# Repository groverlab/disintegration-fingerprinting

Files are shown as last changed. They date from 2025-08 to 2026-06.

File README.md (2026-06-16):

# Disintegration Fingerprinting: A Low-Cost and User-Friendly Tool for Identifying Substandard and Falsified Solid-Dosage Medicines

Ishmam Fatima, Oscar Fajardo, Canhui Liu, Harshith Sadhu, and William H. Grover, *Analytical Chemistry* 98 (12), 8871-8892 (2026).
https://doi.org/10.1021/acs.analchem.5c05418

## Usage

If it's not already installed, install *uv* 

MacOS and Linux:

```bash
curl -LsSf https://astral.sh/uv/install.sh | sh
```

Windows:

```powershell
powershell -ExecutionPolicy ByPass -c "irm https://astral.sh/uv/install.ps1 | iex"
```

Program Arduino using the [Arduino IDE](https://www.arduino.cc/en/software/#ide) and the file in df-arduino/df-arduino.ino 

Run acquisition code using

```bash
uv run df-acquire.py
```

Results will be safed in comments.json.gz.

Analyze results using

```base
uv run df-analyze.py path_to_directory
```

where `path_to_directory` is the path to the directory containing the data files to be analyzed.

To recreate all data analysis in the paper, run

```bash
./build.sh
```

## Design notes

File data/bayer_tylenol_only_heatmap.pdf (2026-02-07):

Difference score Tylenol 100248 2027/03 British Columbia

Tylenol EFA114 2028/04 California
Tylenol EFA114 2028/04 Washington

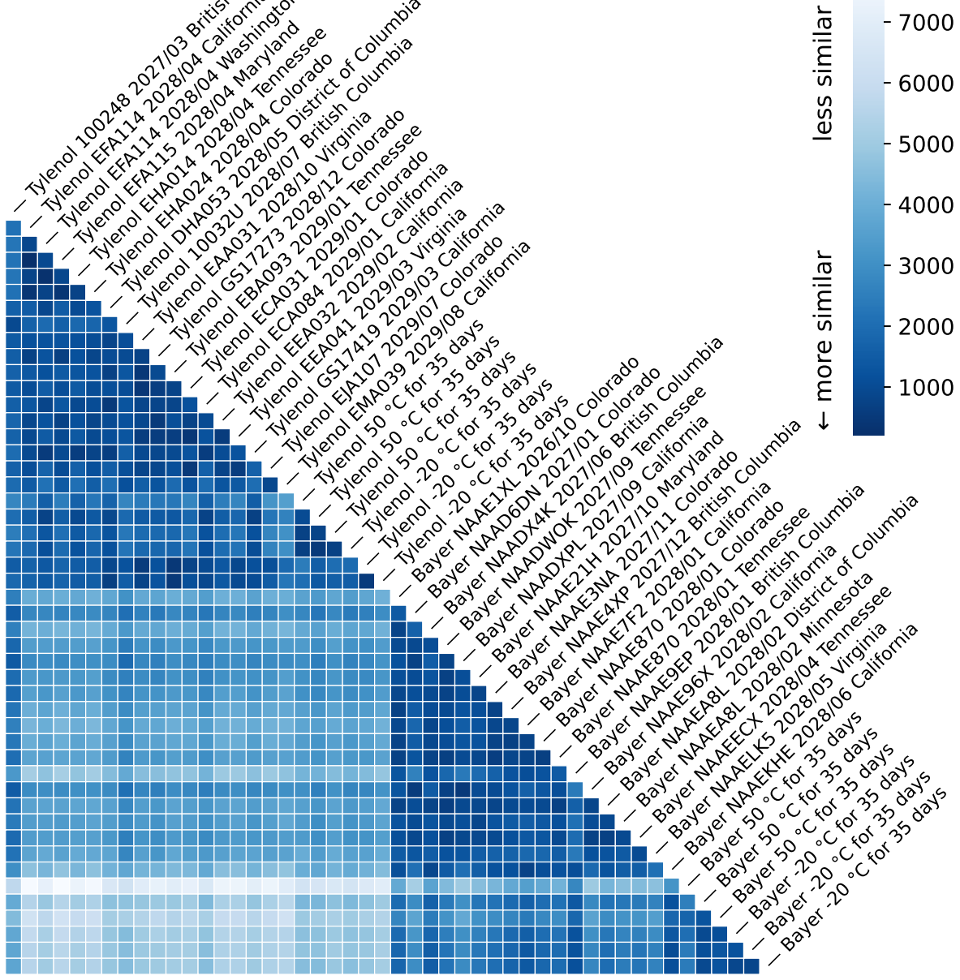
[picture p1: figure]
Tylenol EAA031 2028/10 Virginia; Tylenol GS17273 2028/12 Colorado Tylenol EBA093 2029/01 Tennessee Tylenol ECA031 2029/01 Colorado Tylenol ECA084 2029/01 California Tylenol EEA032 2029/02 California Tylenol EEA041 2029/03 Virginia; Tylenol GS17419 2029/03 California; Tylenol EJA107 2029/07 Colorado Tylenol EMA039 2029/08 California; Tylenol 50 °C for 35 days Tylenol 50 °C for 35 days Tylenol 50 °C for 35 days Tylenol -20 °C for 35 days Tylenol -20 °C for 35 days Tylenol -20 °C for 35 days; Bayer NAAE1XL 2026/10 Colorado Bayer NAAD6DN 2027/01 Colorado; Bayer NAADX4K 2027/06 British Columbia; Bayer NAADWOK 2027/09 Tennessee Bayer NAADXPL 2027/09 California Bayer NAAE21H 2027/10 Maryland Bayer NAAE3NA 2027/11 Colorado; Bayer NAAE4XP 2027/12 British Columbia; Bayer NAAE7F2 2028/01 California Bayer NAAE870 2028/01 Colorado Bayer NAAE870 2028/01 Tennessee; Bayer NAAE9EP 2028/01 British Columbia; Bayer NAAE96X 2028/02 California Bayer NAAEA8L 2028/02 Minnesota Bayer NAAEECX 2028/04 Tennessee; Bayer NAAELK5 2028/05 Virginia Bayer NAAEKHE 2028/06 California; Bayer 50 °C for 35 days Bayer 50 °C for 35 days Bayer 50 °C for 35 days Bayer -20 °C for 35 days Bayer -20 °C for 35 days Bayer -20 °C for 35 days; more similar less similar

Tylenol EFA115 2028/04 Maryland
Tylenol EHA014 2028/04 Tennessee
Tylenol EHA024 2028/04 Colorado

Tylenol DHA053 2028/05 District of Columbia

Tylenol 10032U 2028/07 British Columbia

Bayer NAAEA8L 2028/02 District of Columbia

6000

7000

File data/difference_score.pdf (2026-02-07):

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

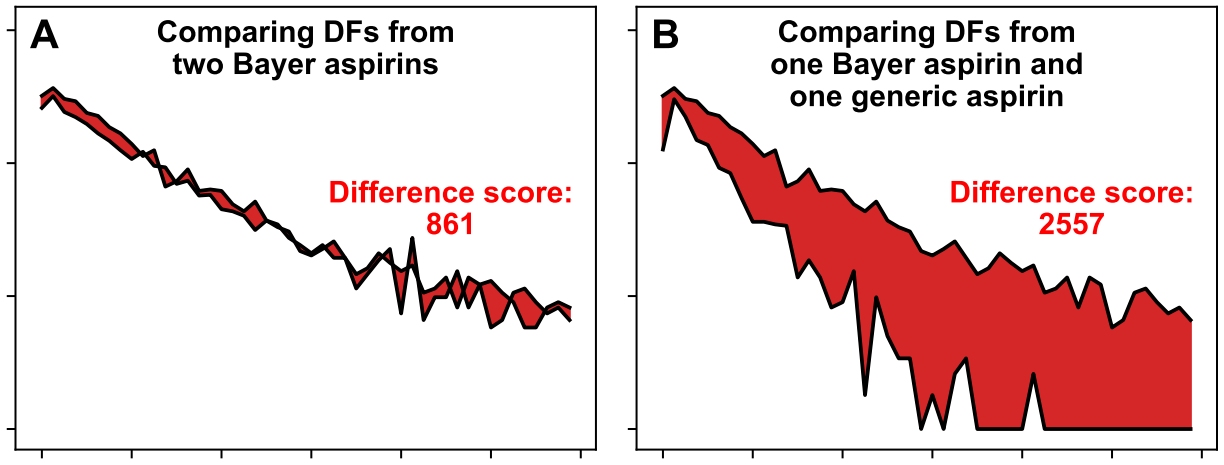
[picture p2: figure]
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

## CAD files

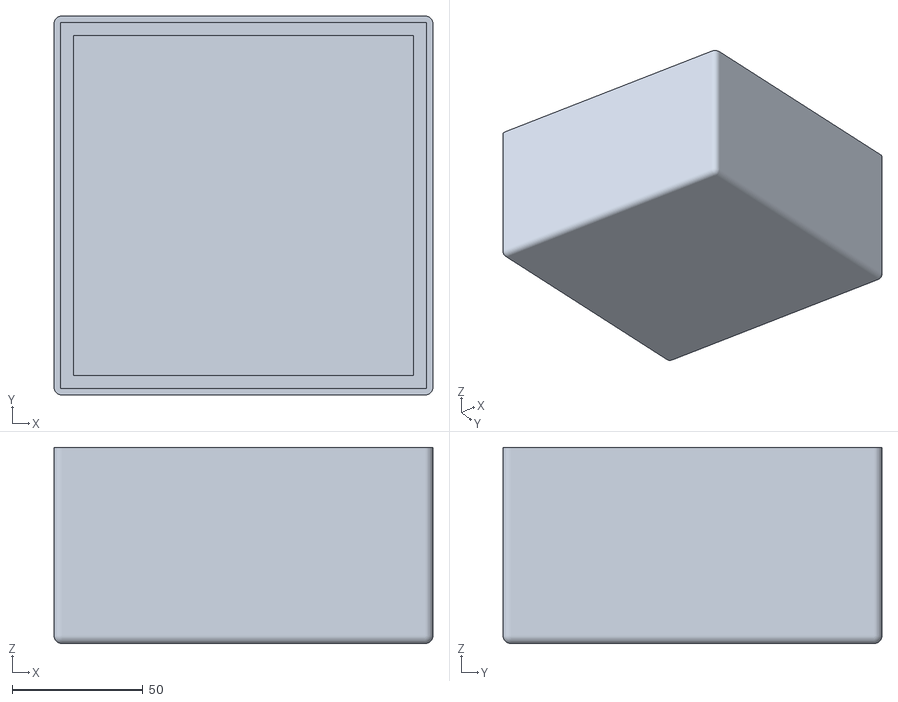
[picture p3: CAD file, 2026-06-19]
3D printing/protective-cap.stl
145.0 x 145.0 x 75.0

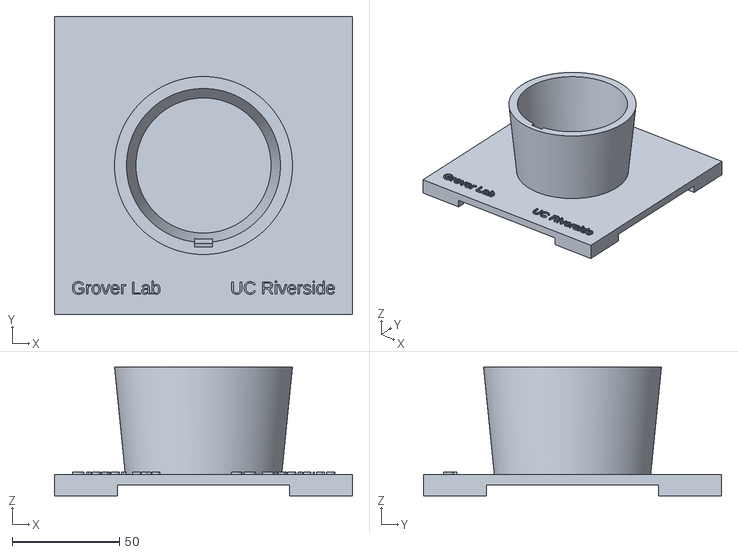
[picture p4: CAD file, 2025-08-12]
3D printing/base.stl
139.0 x 139.0 x 60.0

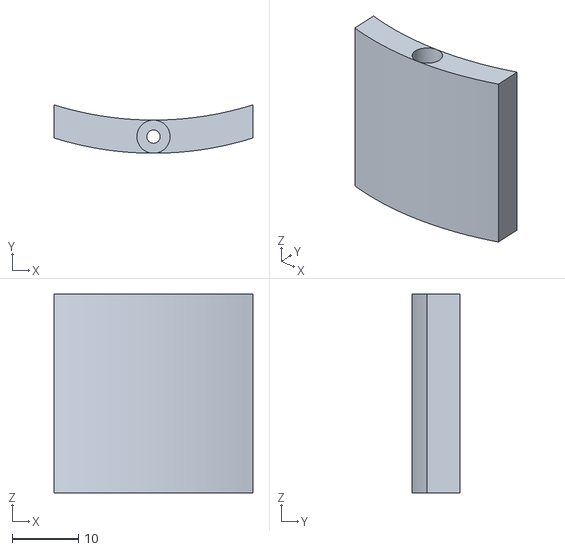
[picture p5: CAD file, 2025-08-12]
3D printing/pill-holder.stl
30.0 x 7.30 x 30.0

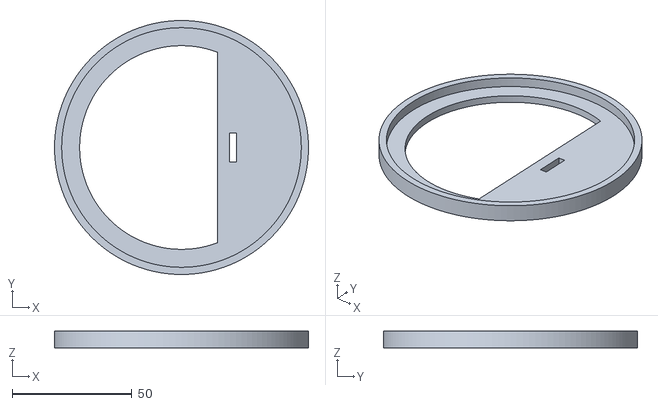
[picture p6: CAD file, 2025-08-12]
3D printing/lid.stl
106.0 x 106.0 x 7.00

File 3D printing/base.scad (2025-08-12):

$fn=120;
difference() {
    cylinder(h=55, d1=72, d2=83);  // outer solid
    translate([0,0,6]) cylinder(h=50, d1=63, d2=72);  // inner cup
    rotate([0,0,-90]) translate([33.5,-4.25,38]) rotate([0,5.0,0]) cube([3, 8.5, 24.5]); // sensor cutout
    }
difference() {
    cube([139, 139, 10], center=true);
    translate([0,0,-5]){ 
        cube([129, 129, 10], center=true);
        cube([139,80,10], center=true);
        cube([80, 139,10], center=true);
        }
    }
translate([0,-60,5]) linear_extrude(1) {
    text("Grover Lab              UC Riverside", 6, halign="center");
    }

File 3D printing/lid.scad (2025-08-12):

$fn=128;

difference() {
    cylinder(h=7, d=106, center=true);
    translate([0,0,1.5]) cylinder(h=4, d=100, center=true);
    cylinder(h=14, d=85, center=true);
    }
difference() {
    translate([0,0,-2]) intersection() {
        cylinder(h=3, d=85, center=true);
        translate([15,-50,-1.5]) cube([100,100, 3]);
    }
    translate([20,-6,-10]) cube([3, 12, 20]);
    }

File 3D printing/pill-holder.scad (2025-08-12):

// cube([30,25, 5]);
height = 30;

$fn=512;
difference() {
    cylinder(d=100, h=height);
    translate([0,5,0]) cylinder(d=100, h=height);
    translate([40,0,0]) cube([50, 100, height*2], center=true);
    translate([-40,0,0]) cube([50, 100, height*2], center=true);
    translate([0,-47.5,27]) cylinder(d=5, h=5);  // servo shaft hole
    translate([0,-47.5,0]) cylinder(d=4, h=26);  // screw access hole
    translate([0,-47.5,0]) cylinder(d=2, h=50);  // screw access hole
    }

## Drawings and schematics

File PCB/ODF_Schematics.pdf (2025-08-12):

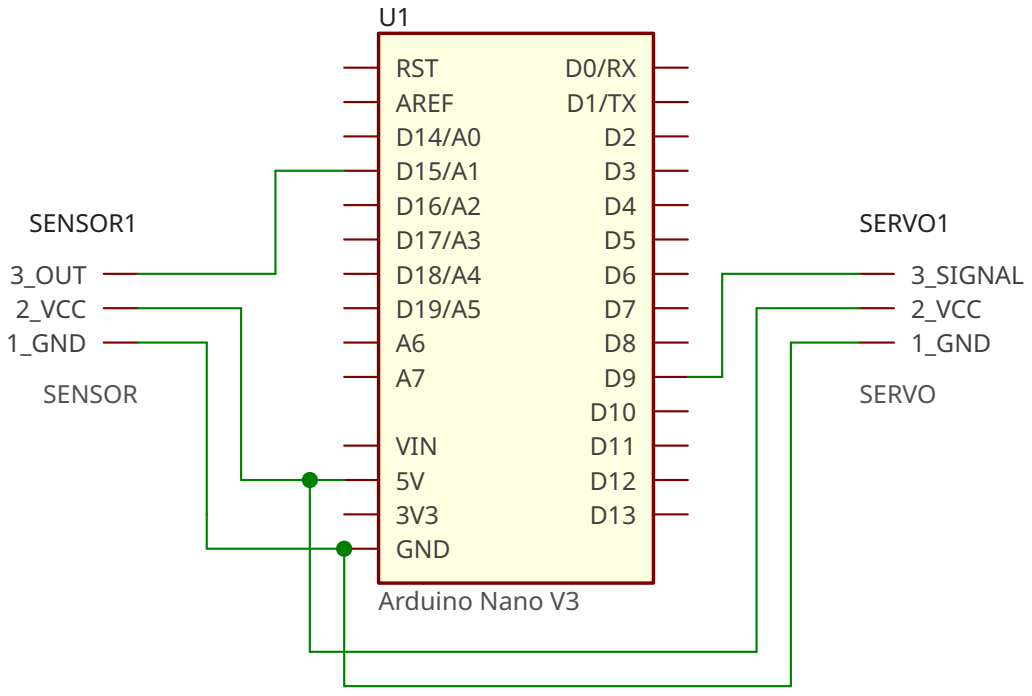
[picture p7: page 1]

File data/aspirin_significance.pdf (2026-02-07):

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

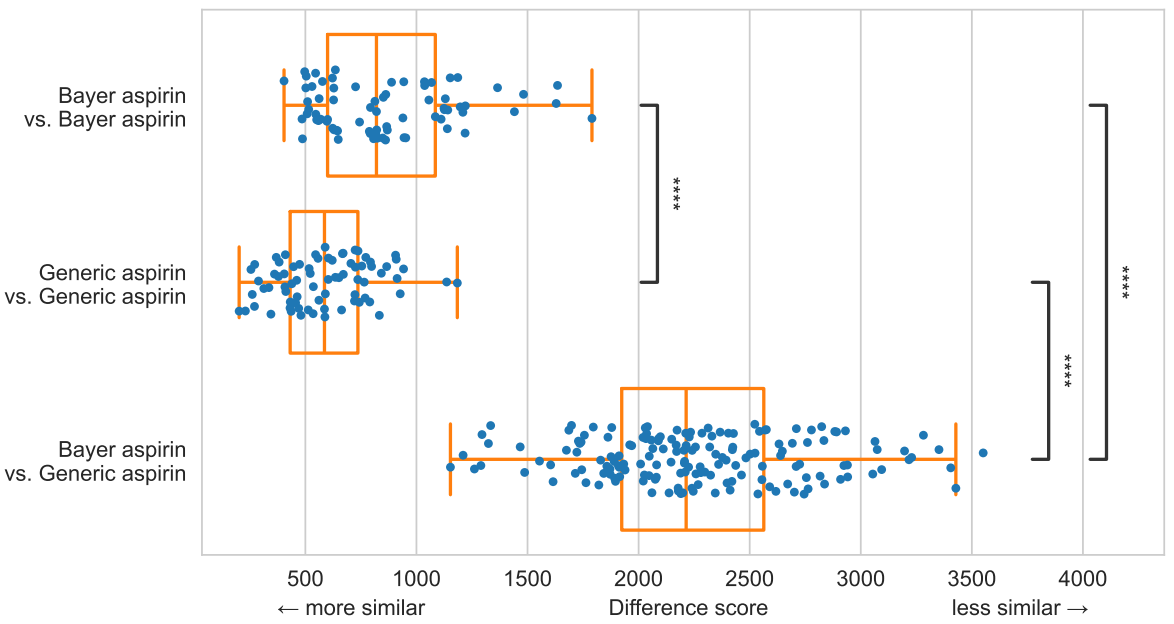
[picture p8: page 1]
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

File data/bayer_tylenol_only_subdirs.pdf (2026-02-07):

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

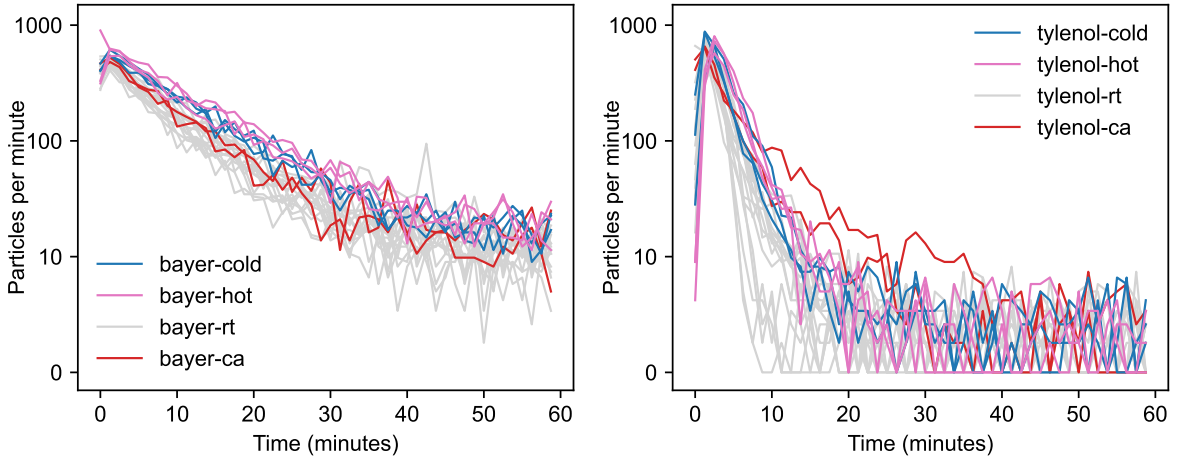
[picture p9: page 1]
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

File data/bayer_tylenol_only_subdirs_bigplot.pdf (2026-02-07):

0

10

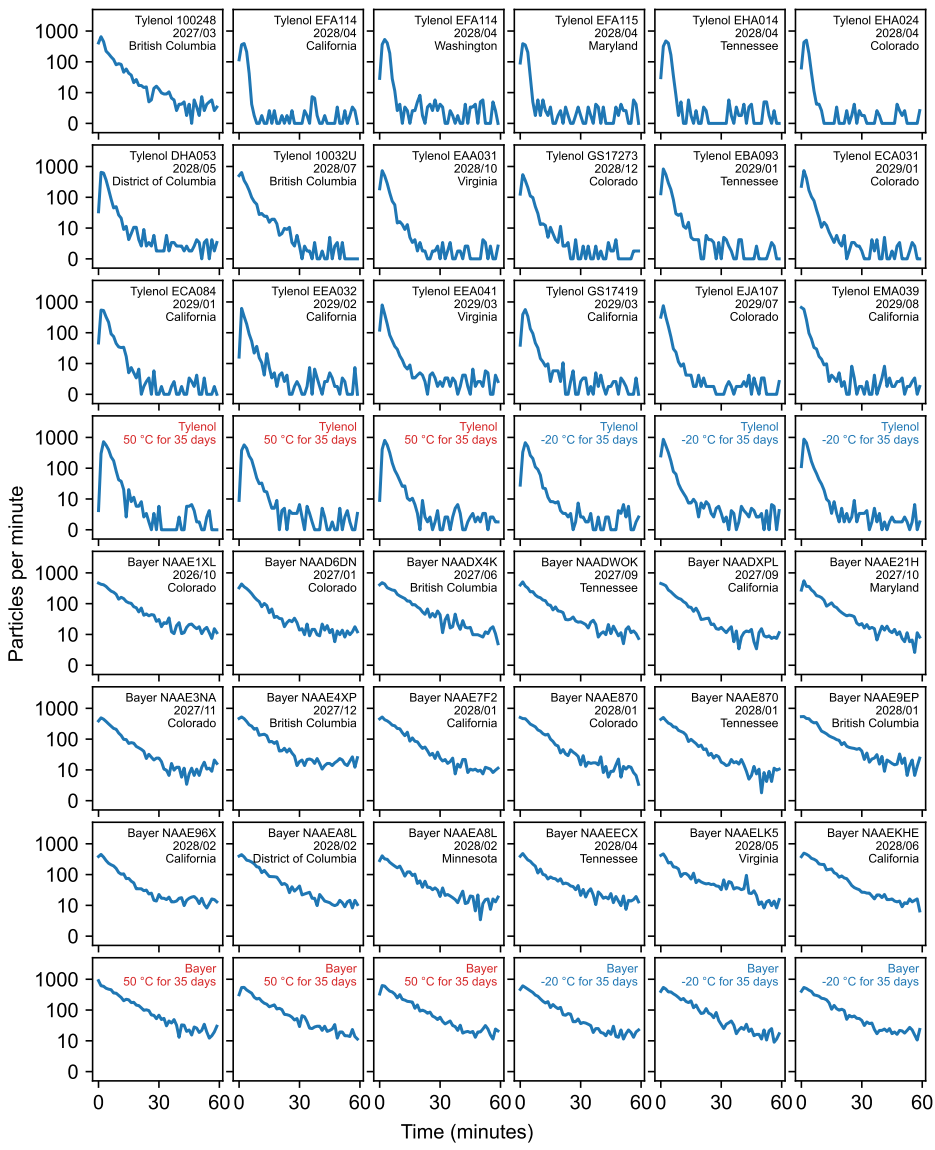
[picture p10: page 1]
Tylenol 100248; 2027/03 British Columbia; Tylenol EFA114 2028/04 California; Tylenol EFA114 2028/04 Washington; Tylenol EFA115 2028/04 Maryland; Tylenol EHA014 2028/04 Tennessee; Tylenol EHA024 2028/04 Colorado; Tylenol DHA053; Tylenol 10032U 2028/07 British Columbia; Tylenol EAA031 2028/10 Virginia; Tylenol GS17273 2028/12 Colorado; Tylenol EBA093 2029/01 Tennessee; Tylenol ECA031 2029/01 Colorado; Tylenol ECA084; 2029/01 California; Tylenol EEA032 2029/02 California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

District of Columbia

Particles per minute

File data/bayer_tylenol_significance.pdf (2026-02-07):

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

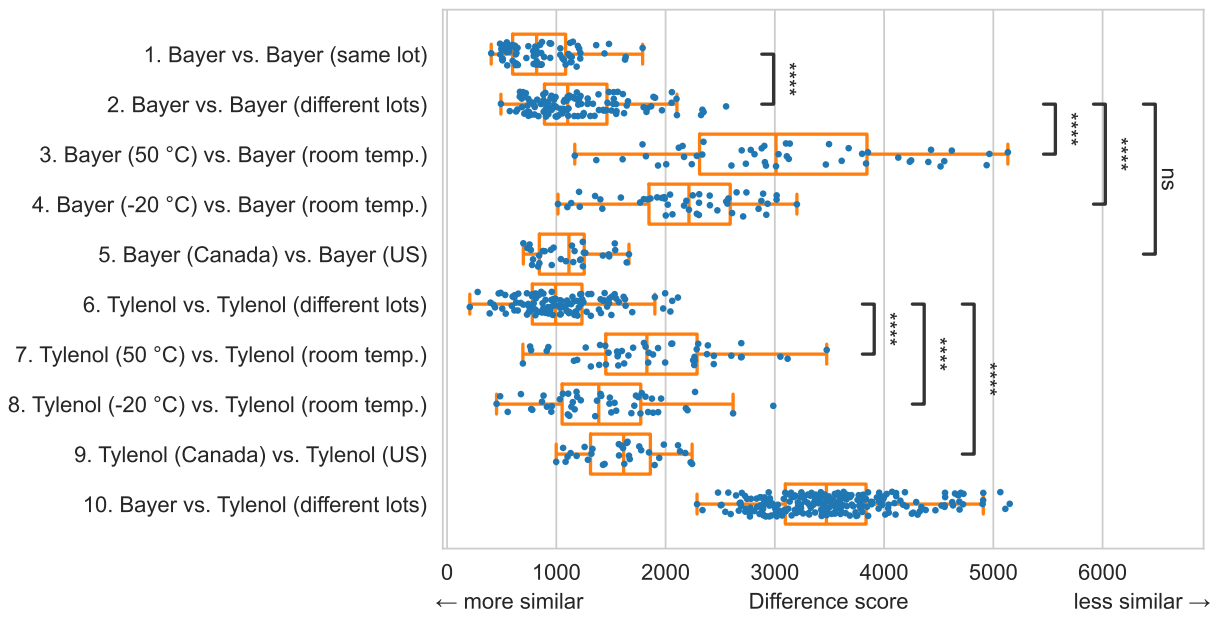
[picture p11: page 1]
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

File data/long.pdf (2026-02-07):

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

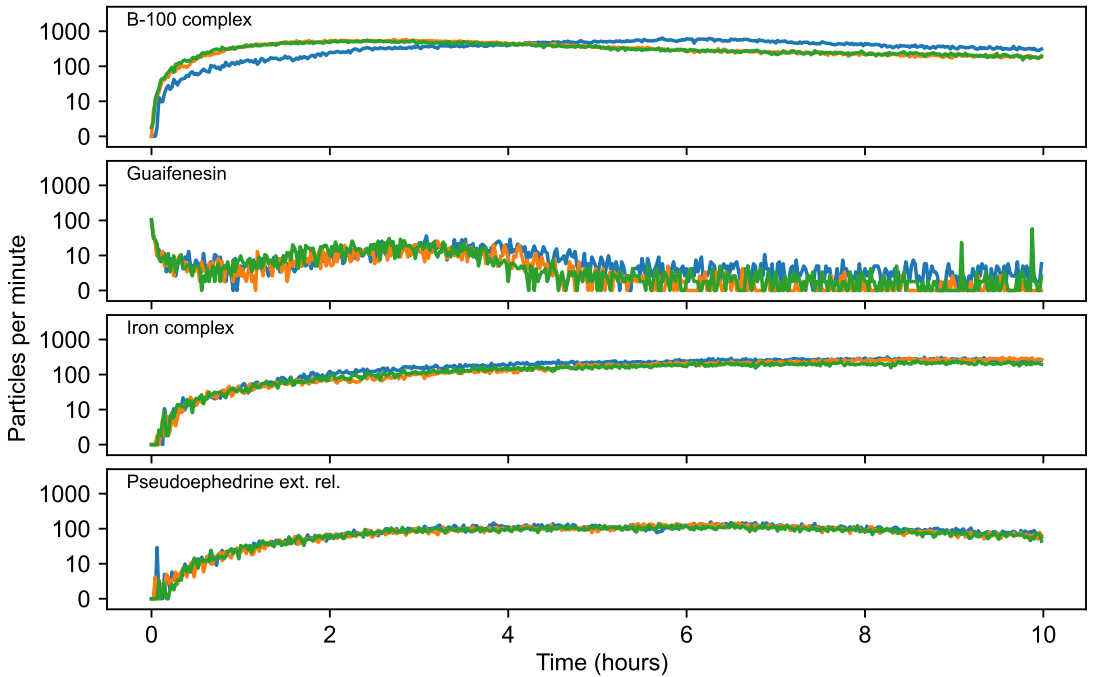
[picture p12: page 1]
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

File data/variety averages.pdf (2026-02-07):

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

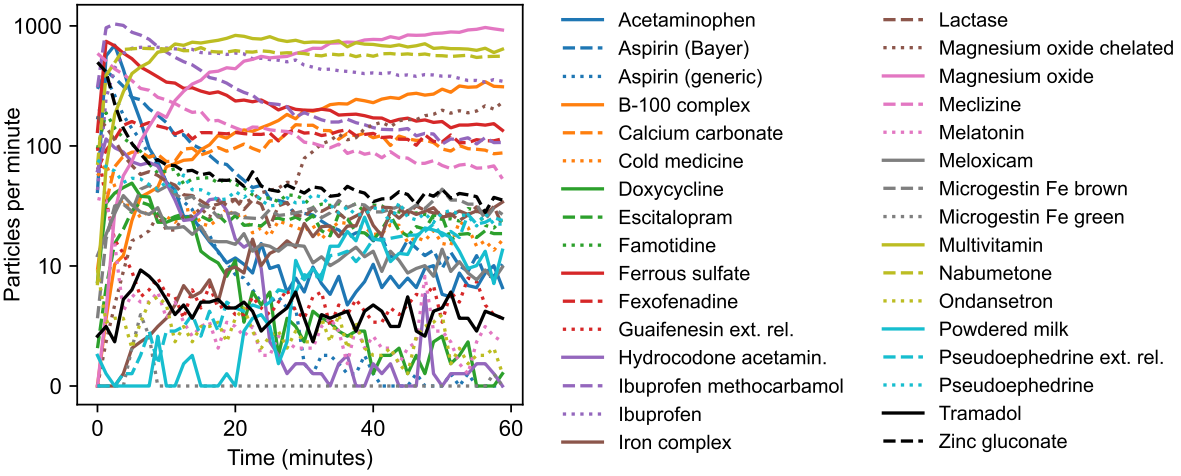
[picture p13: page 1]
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

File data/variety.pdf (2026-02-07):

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

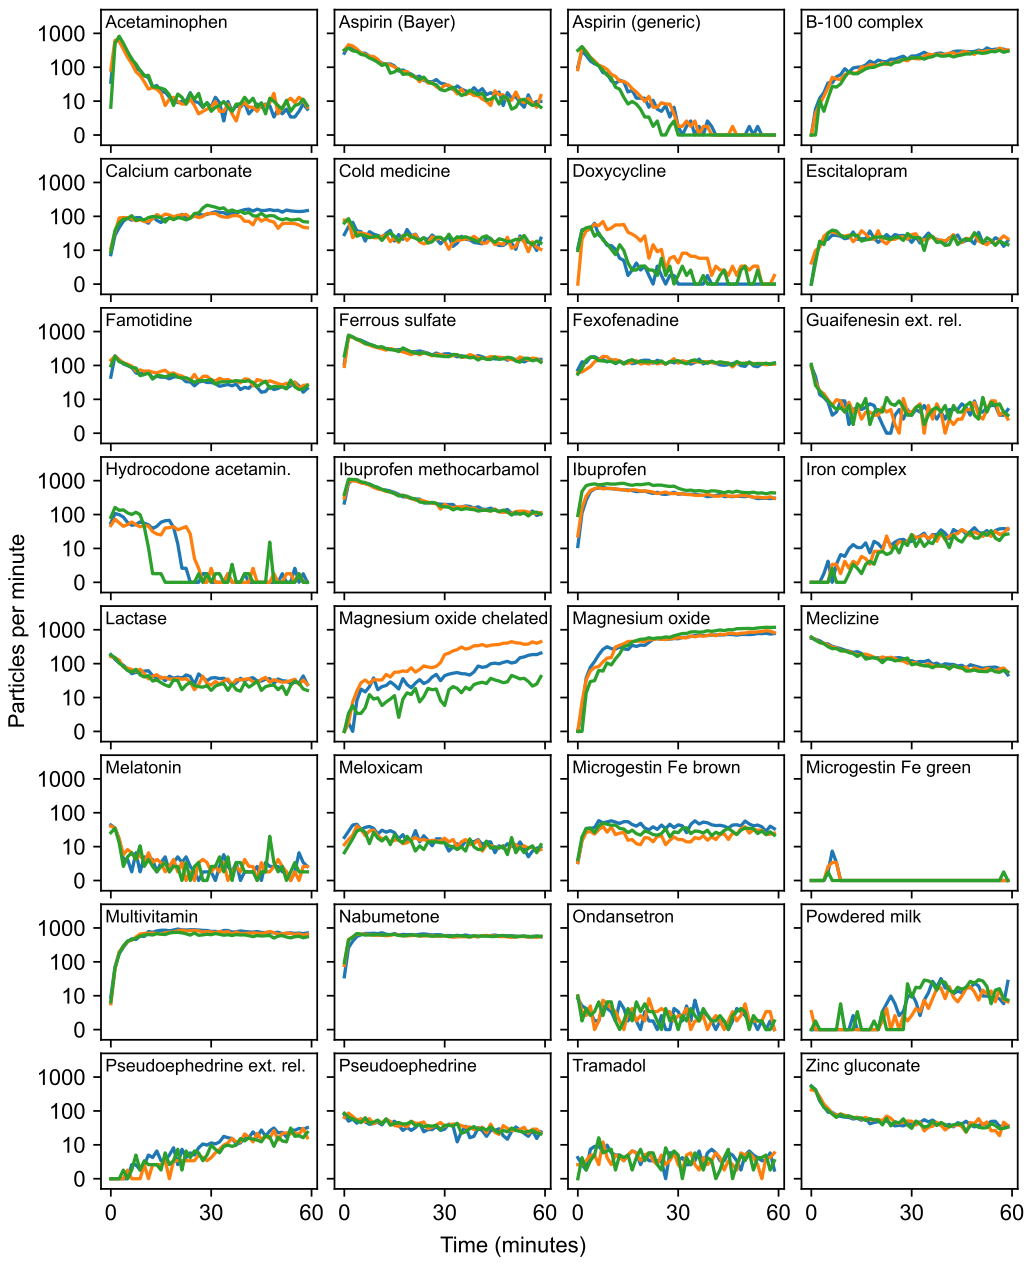
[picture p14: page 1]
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

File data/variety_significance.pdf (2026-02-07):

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

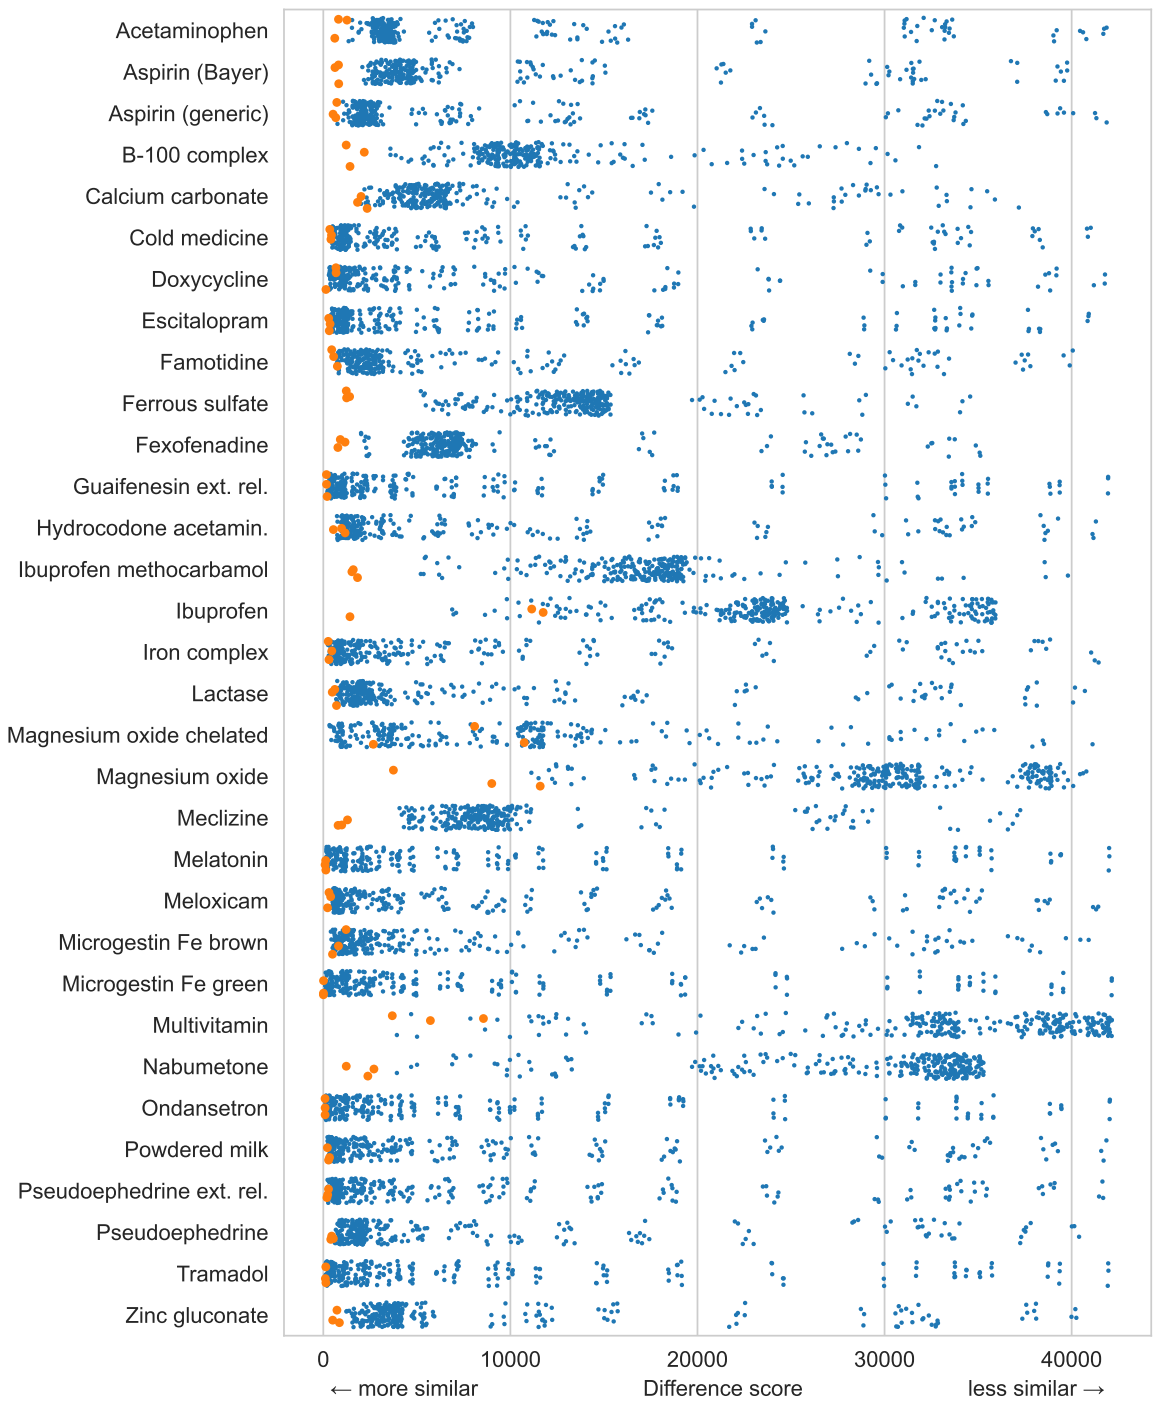
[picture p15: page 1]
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

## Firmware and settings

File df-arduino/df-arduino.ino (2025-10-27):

#include <Servo.h>
Servo servo1;
int incomingByte = 0;

void setup() {
  Serial.begin(115200);
  servo1.attach(9);
  servo1.write(60);
}

void loop() {
  Serial.println(analogRead(A1));
  if (Serial.available() > 0) {
    incomingByte = Serial.read();
    if (incomingByte == '1') {
      servo1.write(60);
    }
    if (incomingByte == '2') {
      servo1.write(90);
    }
  }
}

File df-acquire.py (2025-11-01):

# /// script
# dependencies = ["pyserial"]
# ///

### df-acquire.py by Grover Lab, University of California, Riverside

import sys
import datetime
import time
import platform
import json
import gzip
import argparse

try:
    import serial
    from serial.tools.list_ports import comports
except ImportError:
    sys.exit(
        "❌ Can't find pyserial module - install it by running 'pip install pyserial'"
    )

parser = argparse.ArgumentParser()
parser.add_argument("comments", nargs="?", help="Sample description")
parser.add_argument(
    "-d", "--duration", type=int, help="Run duration [min] or -1 for forever"
)
args = parser.parse_args()


r = {}
if args.comments:
    comments = args.comments.replace(" ", "_")
    print("sample =", comments)
else:
    comments = input("Sample?  ").replace(" ", "_")
r["filename"] = (
    datetime.datetime.now().strftime("%Y%m%dT%H%M%S") + "_" + comments + ".json.gz"
)

ports = 0
port = ""
arduino_ports = []
for p in comports():
    print(str(p))
    if "USB" in str(p) or "usb" in str(p) or "Arduino" in str(p):
        port = p.name
        ports += 1
        arduino_ports.append(port)
if ports == 0:
    sys.exit("❌ No port found - is the Arduino plugged in?")
if ports >= 2:
    print(f"Found Arduinos on these ports:  {arduino_ports}")
    port = input("Which port?  ")
if platform.system() == "Darwin":  # if MacOS...
    port = "/dev/" + port  # ...prepend /dev/
print("✅ Found an Arduino at " + port)

r["port"] = port

r["data"] = []
ser = serial.Serial(port, 115200, timeout=5)

start_time = time.time()
r["start_time"] = str(start_time)

t1 = 300  # duration of baseline phase in seconds; currently 5 minutes or 300 seconds
if args.duration:
    t2 = args.duration * 60 + t1  # set custom dissolution time from command option
else:
    t2 = (
        3600 + t1
    )  # duration of dissolution phase in seconds; currently 60 minutes or 3600 seconds

pill_in = False
errors = 0
ser.flush()
ser.read_all()
while True:
    try:
        s = ser.readline().decode("utf-8", "ignore")
        waiting = ser.inWaiting()
        et = time.time() - start_time
        if 0 <= et < t1:  # baseline phase
            print(
                f"TimeToPill: {str(datetime.timedelta(seconds=t1 - et))[:9]}", end="\t"
            )
        elif t1 <= et < t2:  # dissolution phase
            if not pill_in:
                ser.write(b"2")
                pill_in = True
            print(
                f"TimeToEnd: {str(datetime.timedelta(seconds=t2 - et))[:9]}", end="\t"
            )
        elif et >= t2:  # experiment over
            ser.write(b"1")
            break
        print(f"Port: {port}\tBacklog: {waiting}\tErrors: {errors}\tData: {s}", end="")
        try:
            r["data"].append(int(s))
        except ValueError:
            print("Value error")
            errors += 1
    except KeyboardInterrupt:
        print("quitting now")
        ser.write(b"1")
        break
    except Exception as e:
        errors += 1
r["stop_time"] = str(time.time())
f = gzip.open(r["filename"], "wt")
json.dump(r, f)
f.close()
print("DONE")

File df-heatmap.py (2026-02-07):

import json
import sys
import matplotlib.pyplot as plt
import seaborn as sns
import numpy
from matplotlib.colors import LogNorm
import argparse
import matplotlib.ticker as tkr # Import the ticker module

parser = argparse.ArgumentParser()
parser.add_argument("filename")
parser.add_argument("--figure", default="none", help="figure to generate", choices=["aspirin", "variety", "bayer_tylenol_only"],)
args = parser.parse_args()

f = open(args.filename, 'r')
d = json.load(f)


###### Original version with simple labels:
# bayer_tylenol_data = {
# '011': 'Tylenol',
# '012': 'Tylenol',
# '013': 'Tylenol',
# '101': 'Tylenol 2027/03 BC',
# '102': 'Tylenol 2028/04 CA',
# '103': 'Tylenol 2028/04 WA',
# '104': 'Tylenol 2028/04 MD',
# '105': 'Tylenol 2028/04 TN',
# '106': 'Tylenol 2028/04 CO',
# '107': 'Tylenol 2028/05 DC',
# '108': 'Tylenol 2028/07 BC',
# '109': 'Tylenol 2028/10 VA',
# '110': 'Tylenol 2028/12 CO',
# '111': 'Tylenol 2029/01 TN',
# '112': 'Tylenol 2029/01 CO',
# '113': 'Tylenol 2029/01 CA',
# '114': 'Tylenol 2029/02 CA',
# '115': 'Tylenol 2029/03 VA',
# '116': 'Tylenol 2029/03 CA',
# '117': 'Tylenol 2029/07 CO',
# '118': 'Tylenol 2029/08 CA',
# '150': 'Tylenol HOT 1',
# '151': 'Tylenol HOT 2',
# '152': 'Tylenol HOT 3',
# '153': 'Tylenol COLD 1',
# '154': 'Tylenol COLD 2',
# '155': 'Tylenol COLD 3',
# '411': 'Bayer',
# '412': 'Bayer',
# '413': 'Bayer',
# '501': 'Bayer 2026/10 CO',
# '502': 'Bayer 2027/01 CO',
# '503': 'Bayer 2027/06 BC',
# '504': 'Bayer 2027/09 TN',
# '505': 'Bayer 2027/09 CA',
# '506': 'Bayer 2027/10 MD',
# '507': 'Bayer 2027/11 CO',
# '508': 'Bayer 2027/12 BC',
# '509': 'Bayer 2028/01 CA',
# '510': 'Bayer 2028/01 CO',
# '511': 'Bayer 2028/01 TN',
# '512': 'Bayer 2028/01 BC',
# '513': 'Bayer 2028/02 CA',
# '514': 'Bayer 2028/02 DC',
# '515': 'Bayer 2028/02 MN',
# '517': 'Bayer 2028/04 TN',
# '518': 'Bayer 2028/05 VA',
# '519': 'Bayer 2028/06 CA',
# '550': 'Bayer HOT 1',
# '551': 'Bayer HOT 2',
# '552': 'Bayer HOT 3',
# '553': 'Bayer COLD 1',
# '554': 'Bayer COLD 2',
# '555': 'Bayer COLD 3',
# }

##### This version has improved text labels:
bayer_tylenol_data = {  
'101': 'Tylenol 100248 2027/03 British Columbia',
'102': 'Tylenol EFA114 2028/04 California',
'103': 'Tylenol EFA114 2028/04 Washington',
'104': 'Tylenol EFA115 2028/04 Maryland',
'105': 'Tylenol EHA014 2028/04 Tennessee',
'106': 'Tylenol EHA024 2028/04 Colorado',
'107': 'Tylenol DHA053 2028/05 District of Columbia',
'108': 'Tylenol 10032U 2028/07 British Columbia',
'109': 'Tylenol EAA031 2028/10 Virginia',
'110': 'Tylenol GS17273 2028/12 Colorado',
'111': 'Tylenol EBA093 2029/01 Tennessee',
'112': 'Tylenol ECA031 2029/01 Colorado',
'113': 'Tylenol ECA084 2029/01 California',
'114': 'Tylenol EEA032 2029/02 California',
'115': 'Tylenol EEA041 2029/03 Virginia',
'116': 'Tylenol GS17419 2029/03 California',
'117': 'Tylenol EJA107 2029/07 Colorado',
'118': 'Tylenol EMA039 2029/08 California',
'150': 'Tylenol 50 °C for 35 days',
'151': 'Tylenol 50 °C for 35 days',
'152': 'Tylenol 50 °C for 35 days',
'153': 'Tylenol -20 °C for 35 days',
'154': 'Tylenol -20 °C for 35 days',
'155': 'Tylenol -20 °C for 35 days',
'501': 'Bayer NAAE1XL 2026/10 Colorado',
'502': 'Bayer NAAD6DN 2027/01 Colorado',
'503': 'Bayer NAADX4K 2027/06 British Columbia',
'504': 'Bayer NAADWOK 2027/09 Tennessee',
'505': 'Bayer NAADXPL 2027/09 California',
'506': 'Bayer NAAE21H 2027/10 Maryland',
'507': 'Bayer NAAE3NA 2027/11 Colorado',
'508': 'Bayer NAAE4XP 2027/12 British Columbia',
'509': 'Bayer NAAE7F2 2028/01 California',
'510': 'Bayer NAAE870 2028/01 Colorado',
'511': 'Bayer NAAE870 2028/01 Tennessee',
'512': 'Bayer NAAE9EP 2028/01 British Columbia',
'513': 'Bayer NAAE96X 2028/02 California',
'514': 'Bayer NAAEA8L 2028/02 District of Columbia',
'515': 'Bayer NAAEA8L 2028/02 Minnesota',
'517': 'Bayer NAAEECX 2028/04 Tennessee',
'518': 'Bayer NAAELK5 2028/05 Virginia',
'519': 'Bayer NAAEKHE 2028/06 California',
'550': 'Bayer 50 °C for 35 days',
'551': 'Bayer 50 °C for 35 days',
'552': 'Bayer 50 °C for 35 days',
'553': 'Bayer -20 °C for 35 days',
'554': 'Bayer -20 °C for 35 days',
'555': 'Bayer -20 °C for 35 days',
}


bigtable = numpy.zeros((len(d),len(d)))
smallest = 1e9
largest = 0
for x, l in enumerate(d):
	print()
	print(l)
	for y, i in enumerate(d[l]):
		# print(x, i[1], y, i[3], i[4])  # short
		print(x, i[0], y, i[2], i[4])  # full
		bigtable[x][y] = i[4]
		if i[4] < smallest:
			smallest = i[4]
		if i[4] > largest:
			largest = i[4]

mask = numpy.triu(numpy.ones_like(bigtable, dtype=bool))
fig, ax = plt.subplots(figsize=(7.5,7.5))
plt.axis("off")
# plt.subplots_adjust(left=0.05, right=0.99, top=0.99, bottom=0.01)


if args.figure == "aspirin":
	cbar_ax = ax.inset_axes([0.99, 0.48, 0.04, 0.6])
	heatmapax = sns.heatmap(bigtable, mask=mask, cmap="Blues_r", linewidth=0.5, square=True, cbar_ax=cbar_ax)   # linear scale
	cbar = heatmapax.collections[0].colorbar
	cbar.set_label('← more similar              less similar →', rotation=90, labelpad=-80, size=14)
	cbar.ax.tick_params(labelsize=13)
	plt.text(0.85, 0.95, 'Difference score', horizontalalignment="center", verticalalignment="center", transform=fig.transFigure, size=16)
elif args.figure == "bayer_tylenol_only":
	cbar_ax = ax.inset_axes([1.10, 0.7, 0.04, 0.6])
	heatmapax = sns.heatmap(bigtable, mask=mask, cmap="Blues_r", linewidth=0.5, square=True, cbar_ax=cbar_ax)   # linear scale
	cbar = heatmapax.collections[0].colorbar
	cbar.set_label('← more similar              less similar →', rotation=90, labelpad=-70, size=12)
	cbar.ax.tick_params(labelsize=11)
	plt.text(0.85, 0.97, 'Difference score', horizontalalignment="center", verticalalignment="center", transform=fig.transFigure, size=14)
elif args.figure == "variety":
	formatter = tkr.ScalarFormatter()
	formatter.set_scientific(False)
	cbar_ax = ax.inset_axes([0.94, 0.44, 0.04, 0.6])
	heatmapax = sns.heatmap(bigtable, mask=mask, cmap="Blues_r", linewidth=0.5, norm=LogNorm(), square=True, cbar_ax=cbar_ax, cbar_kws={"format": formatter})   # linear scale
	cbar = heatmapax.collections[0].colorbar
	cbar.set_label('← more similar                           less similar →', rotation=90, labelpad=-75, size=12)
	cbar.ax.tick_params(labelsize=11)
	plt.text(0.85, 0.95, 'Difference score', horizontalalignment="center", verticalalignment="center", transform=fig.transFigure, size=14)
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

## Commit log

2025-08-12 added 3D printing resources
    [base.scad, base.stl, lid.scad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]
2025-08-12 adding material to readme
2025-08-12 added PCB resources
2025-08-14 fixed x-axis scale in variety averages plot
    [df-analyze.py]
2025-10-27 correcting starting position of servo
    [df-arduino.ino]
2025-11-01 patch for rare error on PC
    [df-acquire.py]
2025-12-31 adding heatmaps to build.sh
2025-12-31 fixing bayer-tylenol heatmap
2026-01-11 added additional T13 run to replace rejected
    [df-analyze.py]
2026-01-25 heatmap colorbar improvements
2026-01-25 finalizing heatmaps
2026-06-19 Protective cap for transporting hardware to Africa
    [protective-cap.stl]
